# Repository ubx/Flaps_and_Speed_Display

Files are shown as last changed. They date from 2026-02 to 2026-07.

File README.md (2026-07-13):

# Flaps and Speed Display

An ESP32-S3-based flight instrument displays ([ESP32-S3-Touch-AMOLED-1.75](https://www.waveshare.com/wiki/ESP32-S3-Touch-AMOLED-1.75)) for flaps and speed data.
It uses an AMOLED display with LVGL to provide a graphical gauge for indicated airspeed (IAS) \
and flap position, receiving real-time data via the CAN bus (TWAI).

## Housing
[3D model](housing)

## PCB
[KiCad project](https://github.com/ubx/Flaps_and_Speed_Display_HW)

## Firmware and Polar Data Uploader
[Android app](https://github.com/ubx/Flaps_and_Speed_Display_Uploader) to upload firmware and polar data to the device.

### todo
- ~~adjust speed gauge size and layout~~
- ~~replace the numeric speed field~~
- ~~read and display the actual flap position (flap)~~
- ~~calculate and display the optimal flap position (flaputils::get_optimal_flap)~~
- ~~show display stale when nothing is received after 10 sec~~
- ~~design a graphical actual/optimal display~~
- ~~on start show about screenwith firmware and version~~
- setup screen ~~with brightness~~, ~~select polare~~...
- ~~implement update ventus3_defaut.json OTA with BLE~~
- demo mode
- ~~special flap positions for start and landing~~
- ~~3D print housing~~
- ~~PCB board~~
- ~~User Manual~~
- ~~Altitude screen~~
- ~~PCB rework, make it more professional!~~

Next steps:
- ~~xtent of polar data (JSON files) including speed limitations (minimum, optimal, and never-exceed)~~
- ~~improve speed screen with speed limits~~
- ~~enhance speed screen #1 similar to a real ASI~~

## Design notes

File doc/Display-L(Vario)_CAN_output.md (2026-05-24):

# Display-S(Vario) Settings for a Ventus3

| Index | Volt | Symbol |
|---|-----:|---|
| 0 |  0.0 | L |
| 1 |  0.5 | +2 |
| 2 |  1.3 | +1 |
| 3 |  2.3 | 0 |
| 4 |  3.0 | -1 |
| 5 |  3.3 | -2 |
| 6 |  3.6 | S |
| 7 |  4.0 | S1 |

# CAN Output on CanId 340
````
Frame 97: 16 bytes on wire (128 bits), 16 bytes captured (128 bits) on interface can0, id 0
Controller Area Network, ID: 340 (0x154), Length: 6
CANaerospace Protocol Data
CANaerospace
CAN ID: Flaps Position (340)
Node ID: AHRS (1)
Data Type: UCHAR2 (19)
Service Code: SC0 (0)
Message Code: 95
Data: 131 %, index 2
````
> [!Note]
> ``Data: 131 %`` should read as ``Data: 1.3 V``

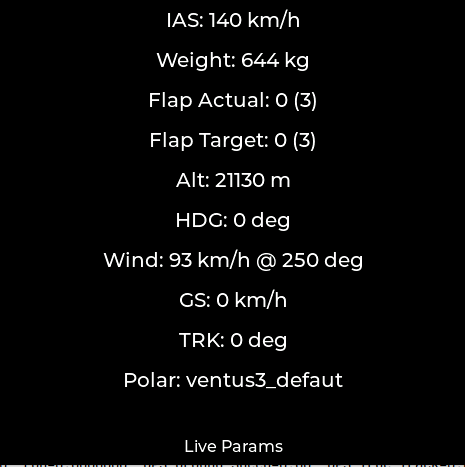
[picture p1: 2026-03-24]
doc/Life_Params.png

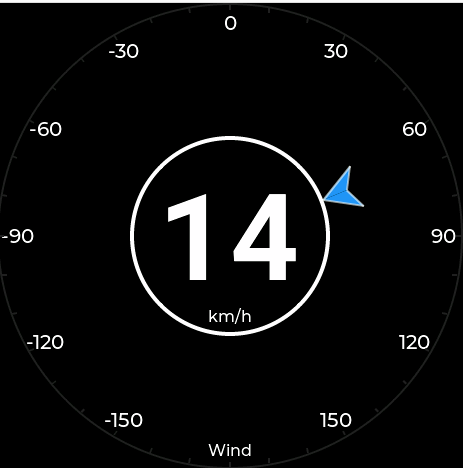
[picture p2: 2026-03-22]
doc/wind.png

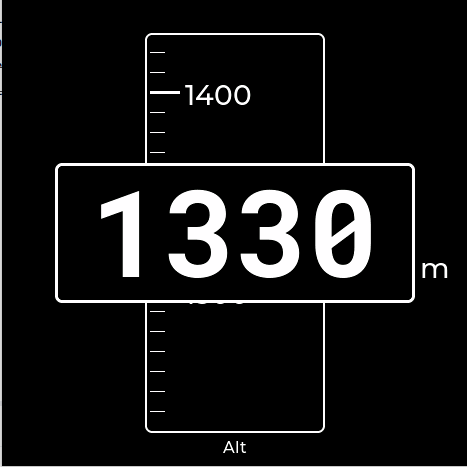
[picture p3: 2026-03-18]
doc/Altitude.png

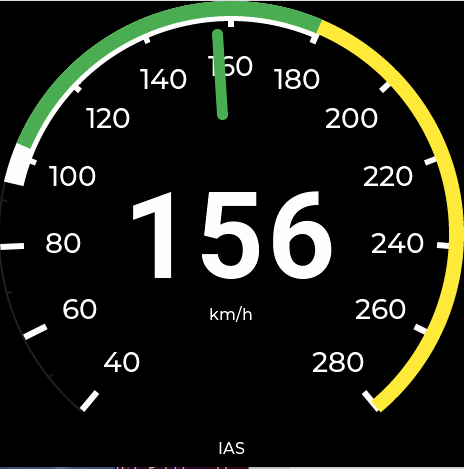
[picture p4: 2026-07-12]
doc/Speed.png

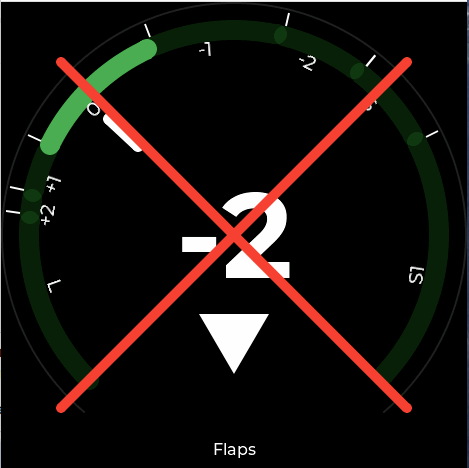
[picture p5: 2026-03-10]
doc/Flaps-Stale.png

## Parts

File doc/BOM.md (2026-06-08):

| # | Qty | Component | Size | Description  |
|---|-----|---|---|---|
| 1 | 3 | Linsenkopfschraube | M2 x 5 0 | ------------ |
 |

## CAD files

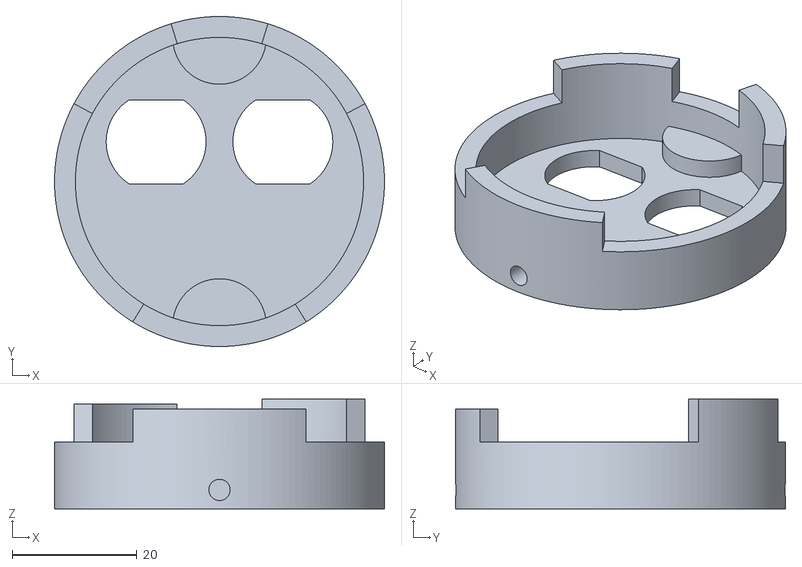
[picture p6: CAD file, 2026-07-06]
housing/57mm Instrument Flaps&Speed - Part 3.stl
52.9 x 52.9 x 17.6

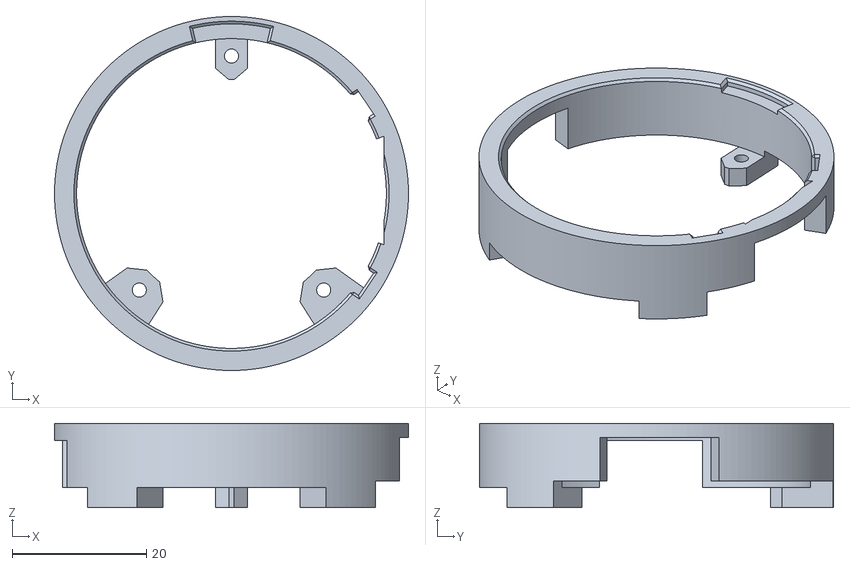
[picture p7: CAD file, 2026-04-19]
housing/57mm Instrument Flaps&Speed - Part 2.stl
52.8 x 52.8 x 12.6

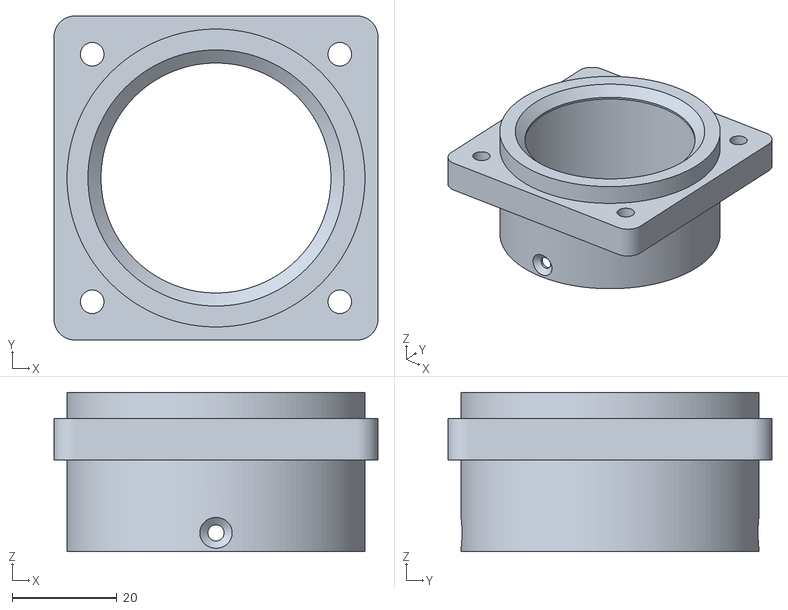
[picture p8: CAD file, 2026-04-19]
housing/57mm Instrument Flaps&Speed - Part 1.stl
62.0 x 62.0 x 30.5

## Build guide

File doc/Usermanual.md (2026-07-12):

# Flaps & Speed Display User Manual

**Document version:** 1.1  
**Date:** 24.03.2026

## Purpose

The **Flaps & Speed Display** is a touchscreen flight display for the ESP32-S3 AMOLED unit. It receives live data from the CAN bus and shows:

- indicated airspeed (IAS)
- current flap setting
- recommended flap setting
- flight altitude
- wind information (speed and relative direction)
- display brightness settings

The display is controlled entirely by touch gestures and on-screen buttons.

## Startup

After power-up, the unit shows a short splash screen with:

- application name
- firmware version
- git revision

It then switches to the normal operating screens.

## Touch Navigation

The display has seven screens. Navigation is done with swipe gestures:

- **Swipe up or down**: cycle between the four main flying screens (Speed, Flaps, Altitude, Wind)
- **Swipe right**: open the settings/detail screens
- **Swipe right again**: cycle between the three settings/detail screens (Settings, Live Params, Polar Files)
- **Swipe left**: return from the settings/detail screens to the main flying screen

## Screen Overview

### 1. Flaps Screen
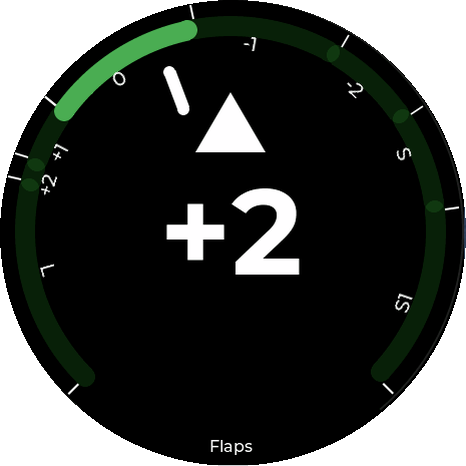
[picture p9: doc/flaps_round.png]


This screen combines airspeed with flap guidance.

- The large text in the center is the **actual flap position symbol**
- The white pointer still shows **IAS**
- The green arc marks the valid speed bands for the flap schedule
- The highlighted arc segment shows the **target flap range**
- The white triangle indicates the correction direction:
  - triangle above: select a **higher** flap setting
  - triangle below: select a **lower** flap setting
  - no triangle: actual and target flap settings match

Typical flap symbols are `L`, `+2`, `+1`, `0`, `-1`, `-2`, `S`, and `S1`.

The current configuration also defines a special **lowspeed** setting in the selected polar file (e.g., `ventus3_defaut.json`):

- flap setting: `-1`
- speed range: `0 to 40 km/h`

This lowspeed setting is intended for takeoff and landing and is handled separately from the normal flap speed bands.

### 2. Speed Screen
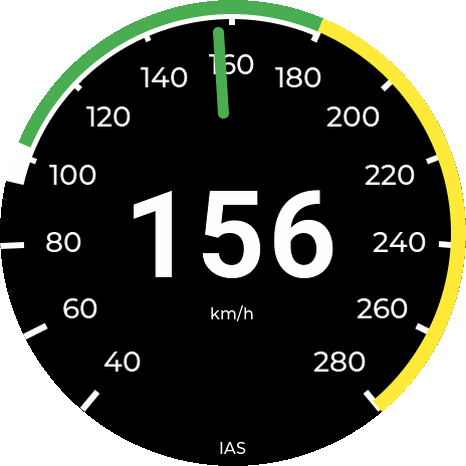
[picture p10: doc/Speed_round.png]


This is the airspeed display.

- The large number in the center is the **indicated airspeed** in **km/h**
- The white pointer shows the same IAS on the circular scale
- The scale range is **40 to 280 km/h**
- The pointer movement is intentionally damped for stable, instrument-like motion

Use this screen when you want the clearest possible IAS indication.

### 3. Altitude Screen
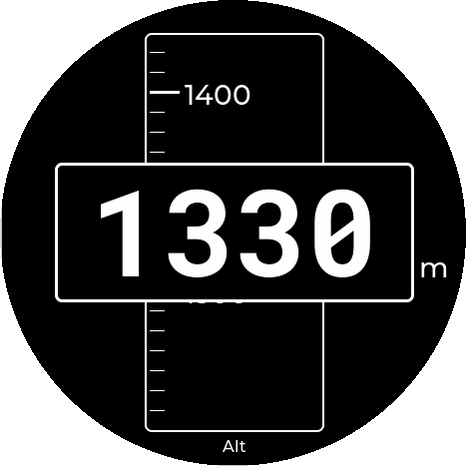
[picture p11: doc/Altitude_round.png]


This screen displays the current flight altitude.

- The large number in the center is the **altitude** in **meters**
- The moving tape in the center provides a visual representation of altitude changes
- The tape has major markings every **100 meters** and minor markings every **10 meters**
- The current altitude is also shown as a digital value in the center box for better readability

### 4. Wind Screen
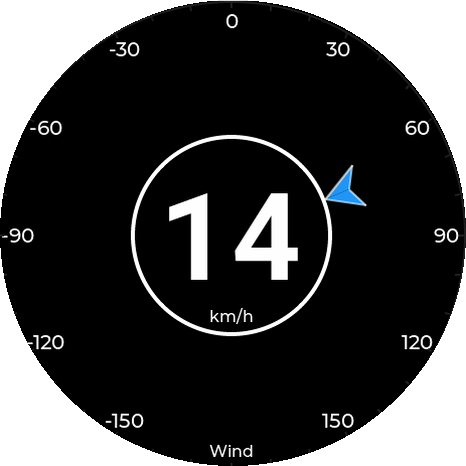
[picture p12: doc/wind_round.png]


This screen displays the current wind information relative to the aircraft's heading.

- The large number in the center is the **wind speed** in **km/h**
- The blue arrow on the circular scale shows the **relative wind direction**
- The scale range is **-180° to +180°** (0° is straight ahead)
- The arrow points in the direction the wind is coming from relative to the nose of the aircraft

### 5. Live Params Screen
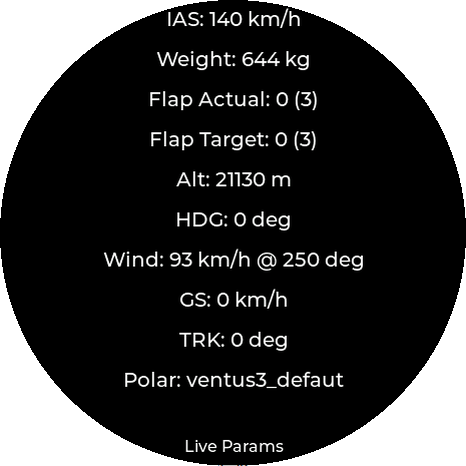
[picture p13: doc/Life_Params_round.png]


This screen shows the values used internally for flap guidance and navigation.

- **IAS**: indicated airspeed in km/h
- **Weight**: current flying weight used for the flap calculation
- **Flap Actual**: current detected flap symbol and index
- **Flap Target**: recommended flap symbol and index
- **Alt**: current altitude in meters
- **HDG**: current heading in degrees
- **Wind**: wind speed and absolute direction
- **GS**: ground speed in km/h
- **TRK**: GPS true track in degrees
- **Polar**: currently active flap schedule (polar file name)

This is the best screen for troubleshooting or checking why a flap recommendation or wind calculation is being made.

### 6. Settings / Brightness Screen
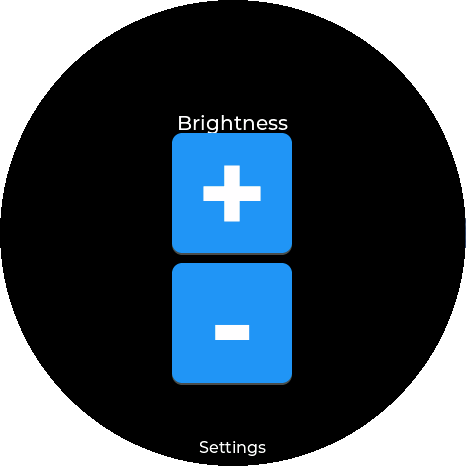
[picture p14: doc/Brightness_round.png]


This screen is used to adjust the display brightness.

- Press `+` to increase brightness
- Press `-` to decrease brightness

Brightness changes in **10% steps**.

- minimum brightness: **30%**
- maximum brightness: **100%**

### 7. Polar Files Screen
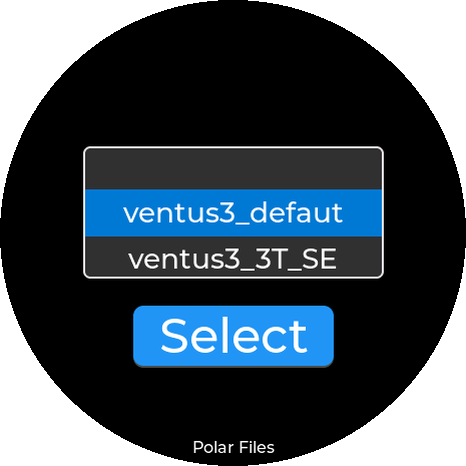
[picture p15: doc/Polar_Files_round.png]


This screen allows you to select the aircraft's polar file (flap schedule) from the files stored in the unit's internal memory (SPIFFS).

- The **roller** in the center lists all available `.json` files
- Use your finger to scroll through the list
- Press the **Select** button to load the highlighted polar

Once selected, the new polar is active immediately and will be remembered across power cycles.

#### Polar File: Speed Limits (`speedlimits`)

| Field | Meaning | Example value [km/h] |
| --- | --- |---:|
| **vso** | Stall speed in the landing configuration (full flaps, gear as applicable) | 94 |
| **vs1** | Stall speed in the clean configuration (flaps up) | 103 |
| **vfe** | Maximum flap extended speed | 180 |
| **vno** | Maximum structural cruising speed | 180 |
| **vne** | Never exceed speed | 280 |

See [Airspeed indicator](https://en.wikipedia.org/wiki/Airspeed_indicator). 
Values for a [Ventus-3F](https://www.google.com/url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)
and *FLUGHANDBUCH Ventus-3F „Sport“*

## How Flap Guidance Works

The unit compares:

- current IAS from CAN bus data
- current flap position from CAN bus data
- current weight from CAN bus data
- the flap schedule in the selected polar file (stored in SPIFFS)

## Stale Data Indication

If no relevant live data is received for **10 seconds**, the display marks the active flying screen as stale.

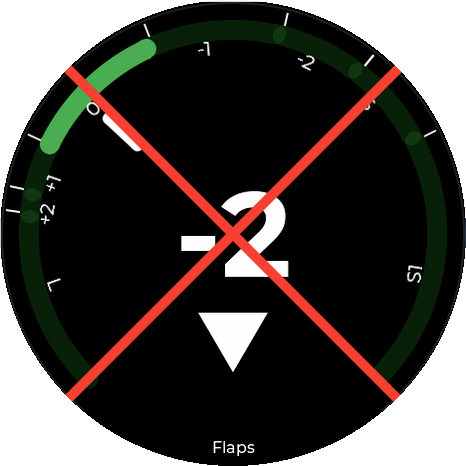
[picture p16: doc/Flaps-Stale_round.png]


The stale condition is shown by a large **red X** across the active screen.

This indicates that the shown IAS/flap information should no longer be trusted until valid CAN data is received again.

## Normal Use

1. Power on the unit.
2. Wait until the splash screen finishes.
3. Use the **Speed** screen for normal IAS monitoring.
4. Swipe to the **Flaps** screen when flap guidance is needed.
5. Swipe to the **Altitude** screen for height monitoring.
6. Swipe to the **Wind** screen to check wind conditions.
7. Open **Live Params** if you want to verify internal values.
8. Open **Polar Files** to select the correct aircraft model.
9. Open **Settings** to adjust brightness for cockpit conditions.

## Notes

- All speed values are displayed in **km/h**
- Flap recommendations depend on the flap polar stored in the JSON configuration
- If flap input data does not match a known position, the flap indication may show no valid symbol
- The guidance described in this manual is based on the Ventus 3 reference shown below (typically found in `ventus3_defaut.json`)
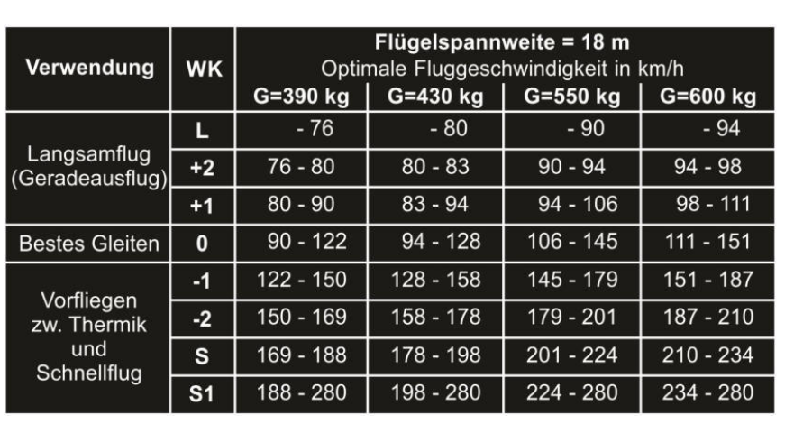
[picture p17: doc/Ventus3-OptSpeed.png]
-

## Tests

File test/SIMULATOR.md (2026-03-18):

# Simulator

`test/simulator.py` generates CAN frames directly on `can0`. It does not read from a log file.

## Sweep

The script iterates through this parameter sweep:

- `dry_and_ballast_mass`: `380` to `600 kg` (sent as `3800` to `6000`), increment `20` (`200`)
- `flaps`: `94, 167, 243, 84, 156, 191, 230, 250`
- `ias`: `10` to `280 km/h`, increment `10`

For each `(dry_and_ballast_mass, flaps, ias)` combination, it sends these CAN frames in order:

1. `dry_and_ballast_mass` on CAN ID `1515`
2. `flaps` on CAN ID `340`
3. `ias` on CAN ID `315`
4. `alt` on CAN ID `322`

## Encoding

- `dry_and_ballast_mass`: stored as big-endian unsigned 16-bit value in bytes `4..5` (value is 10 * kg)
- `flaps`: stored in byte `4`
- `ias`: input is in `km/h`, encoded as big-endian float in `m/s` in bytes `4..7`
- `alt`: input is in `m`, encoded as big-endian float in bytes `4..7`

Unused bytes are set to `0`.

## Timing

- `--time-gap <seconds>`: delay between each generated combination
- `--loop`: repeat the full sweep indefinitely

Without `--loop`, the script runs the sweep once and exits.

## Example

```bash
cd ..
python3 test/simulator.py --time-gap 1.0 --loop
```

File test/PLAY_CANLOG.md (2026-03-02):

### CAN Log Player Tool (`play_canlog.py`)

This document describes the `play_canlog.py` test tool, which simulates a CAN bus by playing back recorded messages from `canlog.log`.

### Overview
The `play_canlog.py` script reads the standard SocketCAN log format and sends the messages to the `can0` interface. It maintains the original timing gaps (2 seconds in the current log) between messages and provides decoded information on the terminal.

### Prerequisites

#### 1. Linux SocketCAN
The script uses native Linux SocketCAN support. It requires a `can0` interface to be available.

#### 2. Virtual CAN (vcan0) Setup
If you don't have a physical CAN interface, you can set up a virtual one and map it to `can0`. Run the following commands:
```bash
sudo modprobe vcan
sudo ip link add dev can0 type vcan
sudo ip link set up can0
```

### Usage

1. **Make the script executable**:
   ```bash
   chmod +x test/play_canlog.py
   ```

2. **Run the script**:
   ```bash
   cd ..
   ./test/play_canlog.py
   ```

3. **Optional Arguments**:
   - `--time-gap SECONDS`: Override the timing from the log file with a fixed delay between messages.
     ```bash
     cd ..
     ./test/play_canlog.py --time-gap 25
     ```

   - `--loop`: Loop the log file infinitely.
     ```bash
     cd ..
     ./test/play_canlog.py --loop
     ```

### Input File: `canlog.log`
The script reads from `test/canlog.log`. The log contains:
- **Flap positions** (ID 154 / 0x154): Values from `test_flaputils.cpp`.
- **Mass** (ID 1515 / 0x5EB): Constant value 4100.
- **IAS** (ID 315 / 0x13B): Ranging from 10 to 80 m/s with an increment of 3.

### Decoded Output
For each message sent, the script prints:
- The absolute timestamp from the log.
- The CAN ID and raw hex data.
- The human-readable parameter name and value (decoded according to `src/main.cpp`).

**Example output**:
```text
Playing test/canlog.log on can0...
[1740476040.000000] Sent ID 154 Data 000000005E000000 (flap: 94)
[1740476042.000000] Sent ID 5EB Data 0000000010040000 (dry_and_ballast_mass: 4100 Hg)
[1740476044.000000] Sent ID 13B Data 0000000041200000 (ias: 10.00 m/s)
...
```

### Notes
- The script uses **standard 11-bit CAN IDs** (non-extended).
- Multi-byte values (IAS, Mass) are encoded in **Big-Endian** format at byte index 4 of the CAN payload.

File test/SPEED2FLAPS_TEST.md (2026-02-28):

### SPEED2FLAPS_TEST

`speed2flaps_teste.py` is a PySide6-based graphical control panel used to simulate flight data (IAS, Mass, and Flaps) and transmit it over a SocketCAN interface. This tool is designed to test the `Flaps_and_Speed_Display` firmware by mimicking real-time CAN messages from a flight computer.

#### Features
- **IAS Control**: Adjust Indicated Airspeed (40–279 km/h). Sends CAN ID `315` (float, m/s).
- **Mass Control**: Adjust Glider Mass (390–600 kg). Sends CAN ID `1515` (uint16, Hg).
- **Flaps Control**: Select from predefined flap sensor voltage values. Sends CAN ID `340` (uint8).
- **Real-time Transmission**: Automatically sends CAN frames to the `can0` interface upon any value change.

#### Requirements
- Python 3
- PySide6
- A Linux system with `can0` or `vcan0` configured.

#### Usage
```bash
cd ..
python3 test/speed2flaps_teste.py
```

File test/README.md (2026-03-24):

This directory contains the test suite for the `flaputils` library.

### How to run the test on Native Platform

#### Option A: PlatformIO (Recommended)
1. Ensure you have PlatformIO installed (`pip install platformio`).
2. Build the native environment:
   ```bash
   cd ..
   pio run -e native
   ```
3. Run the compiled program:
   ```bash
   cd ..
   .pio/build/native/program
   ```
   *Note: Ensure you are in the project root directory so the program can find `spiffs_data/ventus3_defaut.json`.*

#### Option B: Plain g++
1. Install `cJSON` (e.g., `sudo apt-get install libcjson-dev` on Ubuntu).
2. Compile from the project root:
   ```bash
   cd ..
   g++ -std=c++17 -DNATIVE_TEST_BUILD -Isrc \
       test/test_flaputils.cpp src/flaputils.cpp \
       -lcjson -o test_flaputils
   ```
3. Run the executable:
   ```bash
   cd ..
   ./test_flaputils
   ```

### Notes
- The test loads data from `spiffs_data/ventus3_defaut.json`.
- It verifies empty mass, flap symbol lookup, and optimal flap interpolation.
- The same test file can also be run on ESP-IDF targets.

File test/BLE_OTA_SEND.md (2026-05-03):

# BLE OTA Sender (`test/ble_ota_send.py`)

This script sends data to the ESP32 BLE OTA service.

It supports two modes:

1. App firmware OTA (`--bin`)
2. SPIFFS file upload (`--spiffs-file` or `--spiffs-dir`)

Exactly one mode must be selected.

## Requirements

- Device is running firmware with BLE OTA service enabled.
- Device advertises as `Flaps-OTA` (or pass `--name` / `--address`).
- Python environment has `bleak` installed.

## Basic Usage

### 1) Firmware OTA (app partition)

```bash
cd ..
python test/ble_ota_send.py --bin .pio/build/esp32-s3-flaps/firmware.bin
```

Behavior:

- Sends `START` with size + CRC32.
- Streams firmware chunks over BLE.
- Sends `FINISH`.
- Sends `REBOOT` unless `--no-reboot` is set.

### 2) Upload SPIFFS files

#### Single file (`ventus3_defaut.json`)

```bash
cd ..
python test/ble_ota_send.py --spiffs-file spiffs_data/ventus3_defaut.json
```

Default remote target path: `/spiffs/ventus3_defaut.json`

#### Multiple files

```bash
cd ..
python test/ble_ota_send.py \
  --spiffs-file spiffs_data/ventus3_defaut.json \
  --spiffs-file spiffs_data/ventus3_3T_SE.json
```

#### All JSON files in a directory

```bash
cd ..
python test/ble_ota_send.py --spiffs-dir spiffs_data
```

Custom remote path (only for single file):

```bash
cd ..
python test/ble_ota_send.py \
  --spiffs-file spiffs_data/ventus3_defaut.json \
  --spiffs-remote /spiffs/ventus3_defaut.json
```

Behavior:

- Sends `START` with SPIFFS target metadata.
- Streams file content over BLE.
- Sends `FINISH`.
- Does not reboot in SPIFFS mode.

## Options

- `--name <ble_name>`: BLE advertised name (default: `Flaps-OTA`)
- `--address <mac_or_addr>`: connect directly without scanning
- `--bin <firmware.bin>`: firmware OTA mode
- `--spiffs-file <local_path>`: SPIFFS upload mode (can be repeated)
- `--spiffs-dir <dir_path>`: upload all .json files from directory
- `--spiffs-remote <remote_path>`: destination path for single file (default: `/spiffs/<filename>`)
- `--chunk <n>`: transfer chunk size in bytes (default: `240`)
- `--data-with-response`: send DATA writes with response (slower, can be more reliable)
- `--no-reboot`: skip reboot after firmware upload

## Notes

- For firmware mode, a BLE disconnect right after the reboot command can be normal.
- For SPIFFS mode, destination must be under `/spiffs/`.

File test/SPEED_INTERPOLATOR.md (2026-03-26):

### SPEED_INTERPOLATOR

`speed_interpolator.py` is a command-line tool designed to calculate the optimal speed range for a glider based on its current aircraft weight and flap setting. It uses a square-root scaling interpolation method to provide accurate speed recommendations across different weight configurations using data from a polar JSON file.

#### Features
- **Weight-Based Interpolation**: Automatically interpolates between provided weight points in the polar data using square-root scaling.
- **Flap Selection**: Supports various flap settings (e.g., L, +2, 0, -1, S) as defined in the JSON configuration.
- **Clamping**: Automatically clamps to the minimum or maximum weight available in the polar data if the specified weight is out of range.
- **JSON Integration**: Works with the standard glider polar JSON format used in the project.

#### Requirements
- Python 3

#### Usage
The script requires the path to a JSON polar file, the aircraft weight, and the flap setting.

```bash
python3 test/speed_interpolator.py <json_file> --weight <weight_kg> --wk <flap_setting>
```

**Example:**
```bash
cd ..
python3 test/speed_interpolator.py spiffs_data/ventus3_defaut.json --weight 500 --wk +1
```

**Output:**
```text
Weight: 500.0 kg
Flap setting: +1
Recommended speed: 89.6 – 101.2 km/h
```

#### JSON Data Structure
The tool expects a JSON file containing a `speedpolar` section with the following structure:
- `gewicht_kg`: A list of reference weights.
- `bereiche`: A list of flap setting entries, each containing:
    - `wk`: The flap setting identifier.
    - `geschwindigkeit`: A dictionary mapping weight strings to speed range pairs `[min_speed, max_speed]`.

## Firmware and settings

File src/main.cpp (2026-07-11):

#include "flight_data.hpp"
#include "can_decoder.hpp"
#include "flaputils.hpp"
#include "ui/ui.h"
#include "ui/ui_helpers.hpp"
#include "ui/screens/screen1.hpp"
#include "ui/screens/screen2.hpp"
#include "ui/screens/screen3.hpp"
#include "ui/screens/screen4.hpp"
#include "ui/screens/screen5.hpp"
#include "ui/screens/screen6.hpp"
#include "ui/screens/screen7.hpp"

#ifndef NATIVE_TEST_BUILD
#include <cstdio>
#include <cstdint>
#include <mutex>
#include <string>
#include "freertos/FreeRTOS.h"
#include "freertos/task.h"
#include "driver/twai.h"
#include "esp_timer.h"
#include "esp_log.h"
#include "esp_spiffs.h"
#include "esp_task_wdt.h"
#include "nvs_flash.h"
#ifdef ENABLE_DIAGNOSTICS
#include "esp_partition.h"
#include <dirent.h>
#endif
#include "ble_ota.hpp"
#include "bsp/esp32_s3_touch_amoled_1_75.h"
#include "lvgl.h"

#else

#include <algorithm>
#include <atomic>
#include <chrono>
#include <cmath>
#include <csignal>
#include <cstdlib>
#include <cstdio>
#include <cstring>
#include <cerrno>
#include <mutex>
#include <string>
#include <thread>
#include <vector>
#include <sys/ioctl.h>
#include <sys/socket.h>
#include <sys/time.h>
#include <unistd.h>
#include <linux/can.h>
#include <linux/can/raw.h>
#include <net/if.h>
#include "lvgl.h"
#include "platform/ui_platform.hpp"
#include "ui/screens/screen1.hpp"
#include "ui/screens/screen3.hpp"
#include "ui/screens/screen4.hpp"
#endif

#define APP_NAME "Flaps & Speed"
#define APP_VERSION "1.0.4"

#ifndef GIT_REVISION
#define GIT_REVISION "unknown"
#endif

static const char* TAG = "main";
static FlightData g_flight_state;

#ifndef NATIVE_TEST_BUILD

class CANReceiver
{
public:
    CANReceiver(FlightData& flight_data) : flight_data(flight_data) {}

    void start()
    {
        xTaskCreatePinnedToCore(receive_task, "can_rx_task", 4096, this, 5, nullptr, tskNO_AFFINITY);
    }

private:
    FlightData& flight_data;

    static void receive_task(void* arg)
    {
        auto self = static_cast<CANReceiver*>(arg);
        self->run();
    }

    [[noreturn]] void run() const
    {
        twai_message_t message;
        while (true)
        {
            if (twai_receive(&message, pdMS_TO_TICKS(1000)) == ESP_OK)
            {
                handle_message(message);
            }
        }
    }

    void handle_message(const twai_message_t& msg) const
    {
        if (!(msg.flags & TWAI_MSG_FLAG_EXTD))
        {
            switch (msg.identifier)
            {
            case 315: flight_data.update_float("ias", CANDecoder::decode_float(msg.data)); break;
            case 316: flight_data.update_float("tas", CANDecoder::decode_float(msg.data)); break;
            case 321: flight_data.update_float("heading", CANDecoder::decode_float(msg.data)); break;
            case 322: flight_data.update_float("alt", CANDecoder::decode_float(msg.data)); break;
            case 1519: flight_data.update_float("alt_corr", CANDecoder::decode_float(msg.data)); break;
            case 333: flight_data.update_float("wind_speed", CANDecoder::decode_float(msg.data)); break;
            case 334: flight_data.update_float("wind_direction", CANDecoder::decode_float(msg.data)); break;
            case 340: flight_data.update_int("flap", CANDecoder::decode_flap_idx(msg.data)); break;
            case 1039: flight_data.update_float("gps_ground_speed", CANDecoder::decode_float(msg.data)); break;
            case 1040: flight_data.update_float("gps_true_track", CANDecoder::decode_float(msg.data)); break;
            case 1515: flight_data.update_uint16("dry_and_ballast_mass", CANDecoder::decode_u16(msg.data)); break;
            case 1506: flight_data.update_uint16("enl", CANDecoder::decode_u16(msg.data)); break;
            default: break;
            }
        }
    }
};

static CANReceiver receiver(g_flight_state);

static void configure_task_wdt_for_ui(void)
{
#if CONFIG_ESP_TASK_WDT_EN && !CONFIG_FREERTOS_UNICORE
    esp_task_wdt_config_t twdt_cfg = {
        .timeout_ms = CONFIG_ESP_TASK_WDT_TIMEOUT_S * 1000,
        .idle_core_mask = (1U << 0),
#if CONFIG_ESP_TASK_WDT_PANIC
        .trigger_panic = true,
#else
        .trigger_panic = false,
#endif
    };

    esp_err_t ret = esp_task_wdt_reconfigure(&twdt_cfg);
    if (ret == ESP_OK)
    {
        ESP_LOGI(TAG, "Reconfigured TWDT to monitor IDLE0 only");
        return;
    }

    TaskHandle_t idle1 = xTaskGetIdleTaskHandleForCore(1);
    if (!idle1)
    {
        ESP_LOGW(TAG, "IDLE1 handle unavailable; TWDT reconfigure failed: %s", esp_err_to_name(ret));
        return;
    }

    ret = esp_task_wdt_delete(idle1);
    if (ret == ESP_OK || ret == ESP_ERR_NOT_FOUND)
    {
        ESP_LOGI(TAG, "Cleared IDLE1 watchdog subscription");
    }
    else
    {
        ESP_LOGW(TAG, "Failed to clear IDLE1 watchdog subscription: %s", esp_err_to_name(ret));
    }
#endif
}

[[noreturn]] void print_task(void* arg)
{
    auto data = static_cast<FlightData*>(arg);
    while (true)
    {
#ifndef ENABLE_DIAGNOSTICS
        print_flight_data(*data);
#endif
        vTaskDelay(pdMS_TO_TICKS(1000));
    }
}

extern "C" void app_main(void)
{
    configure_task_wdt_for_ui();

    esp_err_t err = nvs_flash_init();
    if (err == ESP_ERR_NVS_NO_FREE_PAGES || err == ESP_ERR_NVS_NEW_VERSION_FOUND)
    {
        ESP_ERROR_CHECK(nvs_flash_erase());
        err = nvs_flash_init();
    }
    ESP_ERROR_CHECK(err);

    vTaskDelay(pdMS_TO_TICKS(2000));

    esp_vfs_spiffs_conf_t conf = {
        .base_path = "/spiffs",
        .partition_label = "spiffs",
        .max_files = 5,
        .format_if_mount_failed = true
    };

    esp_err_t ret = esp_vfs_spiffs_register(&conf);
    if (ret != ESP_OK)
    {
        ESP_LOGE(TAG, "Failed to mount or format SPIFFS (%s)", esp_err_to_name(ret));
    }
    else
    {
        if (flaputils::load_persisted_data())
            ESP_LOGI(TAG, "Persisted polar data loaded successfully");
        else
        {
            std::string first_polar = flaputils::find_first_polar_path();
            if (!first_polar.empty())
            {
                if (flaputils::load_data(first_polar.c_str()))
                {
                    ESP_LOGI(TAG, "No persisted polar, loaded first available: %s", first_polar.c_str());
                    flaputils::save_polar_path(first_polar.c_str());
                }
            }
        }
    }

    ble_ota_init();

    twai_general_config_t g_config = TWAI_GENERAL_CONFIG_DEFAULT(static_cast<gpio_num_t>(TWAI_TX_GPIO),
        static_cast<gpio_num_t>(TWAI_RX_GPIO), TWAI_MODE_NORMAL);
    twai_timing_config_t t_config = TWAI_TIMING_CONFIG_500KBITS();
    twai_filter_config_t f_config = TWAI_FILTER_CONFIG_ACCEPT_ALL();

    if (twai_driver_install(&g_config, &t_config, &f_config) == ESP_OK && twai_start() == ESP_OK)
    {
        receiver.start();
        // xTaskCreate(print_task, "print_task", 4096, &g_flight_state, 2, nullptr);
        ui_init();
        set_label1(APP_NAME);
        set_label2("Version: " APP_VERSION);
        char lvgl_ver[32];
        std::snprintf(lvgl_ver, sizeof(lvgl_ver), "LVGL v%d.%d.%d", LVGL_VERSION_MAJOR, LVGL_VERSION_MINOR, LVGL_VERSION_PATCH);
        set_label3(lvgl_ver);
        set_label4("Git Rev: " GIT_REVISION);
        vTaskDelay(pdMS_TO_TICKS(5000));

        if (bsp_display_lock(-1) == ESP_OK)
        {
            lv_screen_load_anim(screen2_get(), LV_SCR_LOAD_ANIM_FADE_ON, 500, 0, false);
            bsp_display_unlock();
        }
    }
}

#else // NATIVE_TEST_BUILD

struct SimulatorConfig
{
    int start_screen = 2;
    bool auto_cycle = false;
    int cycle_seconds = 8;
    int splash_ms = 1500;
    std::string can_iface = "can0";
};

static std::atomic<bool> g_running{true};
static void handle_signal(int) { g_running = false; }

static int parse_int_arg(const char* value, int fallback) { return value ? std::atoi(value) : fallback; }

static SimulatorConfig parse_args(int argc, char** argv)
{
    SimulatorConfig cfg;
    for (int i = 1; i < argc; ++i)
    {
        if (std::strcmp(argv[i], "--screen") == 0 && i + 1 < argc)
            cfg.start_screen = std::clamp(parse_int_arg(argv[++i], cfg.start_screen), 1, 7);
        else if (std::strcmp(argv[i], "--auto-cycle") == 0)
            cfg.auto_cycle = true;
        else if (std::strcmp(argv[i], "--cycle-seconds") == 0 && i + 1 < argc)
            cfg.cycle_seconds = std::max(1, parse_int_arg(argv[++i], cfg.cycle_seconds));
        else if (std::strcmp(argv[i], "--can-iface") == 0 && i + 1 < argc)
            cfg.can_iface = argv[++i];
        else if (std::strcmp(argv[i], "--no-splash") == 0)
            cfg.splash_ms = 0;
        else if (std::strcmp(argv[i], "--help") == 0)
        {
            std::printf("Usage: %s [--screen 1..7] [--auto-cycle] [--cycle-seconds N] [--can-iface can0] [--no-splash]\n", argv[0]);
            std::exit(0);
        }
    }
    return cfg;
}

static lv_obj_t* get_screen_by_index(int screen)
{
    switch (screen)
    {
    case 1: return screen1_get();
    case 2: return screen2_get();
    case 3: return screen3_get();
    case 4: return screen4_get();
    case 5: return screen5_get();
    case 6: return screen6_get();
    case 7: return screen7_get();
    default: return screen2_get();
    }
}

static void load_screen(int screen, lv_screen_load_anim_t anim)
{
    if (!ui_platform_lock(-1)) return;
    lv_obj_t* target = get_screen_by_index(screen);
    if (target)
    {
#ifdef NATIVE_SIMULATOR
        (void)anim;
        lv_screen_load(target);
#else
        lv_screen_load_anim(target, anim, 250, 0, false);
#endif
    }
    ui_platform_unlock();
}

static int open_can_socket(const std::string& iface)
{
    const int fd = socket(PF_CAN, SOCK_RAW, CAN_RAW);
    if (fd < 0) return -1;

    ifreq ifr {};
    std::snprintf(ifr.ifr_name, IFNAMSIZ, "%s", iface.c_str());
    if (ioctl(fd, SIOCGIFINDEX, &ifr) < 0) { close(fd); return -1; }

    sockaddr_can addr {};
    addr.can_family = AF_CAN;
    addr.can_ifindex = ifr.ifr_ifindex;

    timeval timeout { .tv_sec = 1, .tv_usec = 0 };
    setsockopt(fd, SOL_SOCKET, SO_RCVTIMEO, &timeout, sizeof(timeout));

    if (bind(fd, reinterpret_cast<sockaddr*>(&addr), sizeof(addr)) < 0) { close(fd); return -1; }
    return fd;
}

static void can_receiver_task(std::string iface)
{
    const int fd = open_can_socket(iface);
    if (fd < 0) { g_running = false; return; }

    while (g_running.load())
    {
        can_frame frame {};
        const ssize_t nread = read(fd, &frame, sizeof(frame));
        if (nread < 0) { if (errno == EAGAIN || errno == EWOULDBLOCK) continue; break; }
        if (nread != sizeof(frame) || (frame.can_id & CAN_EFF_FLAG)) continue;

        std::lock_guard lock(g_flight_state.mtx);
        switch (frame.can_id)
        {
        case 315:
            g_flight_state.ias = CANDecoder::decode_float(frame.data);
            g_flight_state.last_relevant_rx_ms = FlightData::monotonic_ms();
            break;
        case 316: g_flight_state.tas = CANDecoder::decode_float(frame.data); break;
        case 321: g_flight_state.heading = CANDecoder::decode_float(frame.data); break;
        case 322: g_flight_state.alt = CANDecoder::decode_float(frame.data); break;
        case 1519: g_flight_state.alt_corr = CANDecoder::decode_float(frame.data); break;
        case 333: g_flight_state.wind_speed = CANDecoder::decode_float(frame.data); break;
        case 334: g_flight_state.wind_direction = CANDecoder::decode_float(frame.data); break;
        case 340:
            g_flight_state.flapIdx = CANDecoder::decode_flap_idx(frame.data);
            g_flight_state.last_relevant_rx_ms = FlightData::monotonic_ms();
            break;
        case 354: g_flight_state.vario = CANDecoder::decode_float(frame.data); break;
        case 1039:
            g_flight_state.gps_ground_speed = CANDecoder::decode_float(frame.data);
            g_flight_state.last_relevant_rx_ms = FlightData::monotonic_ms();
            break;
        case 1040: g_flight_state.gps_true_track = CANDecoder::decode_float(frame.data); break;
        case 1515: g_flight_state.dry_and_ballast_mass = CANDecoder::decode_u16(frame.data); break;
        case 1506: g_flight_state.enl = CANDecoder::decode_u16(frame.data); break;
        default: break;
        }
    }
    close(fd);
    g_running = false;
}

static void pump_ui_for(std::chrono::milliseconds duration)
{
    const auto until = std::chrono::steady_clock::now() + duration;
    while (g_running.load() && std::chrono::steady_clock::now() < until)
    {
        const uint32_t sleep_ms = lv_timer_handler();
        std::this_thread::sleep_for(std::chrono::milliseconds(std::clamp<uint32_t>(sleep_ms, 1, 10)));
    }
}

static void print_task_native(FlightData* data)
{
    while (g_running.load())
    {
        print_flight_data(*data);
        std::this_thread::sleep_for(std::chrono::seconds(1));
    }
}

int main(int argc, char** argv)
{
    std::signal(SIGINT, handle_signal);
    std::signal(SIGTERM, handle_signal);
    const SimulatorConfig cfg = parse_args(argc, argv);

    if (!flaputils::load_persisted_data())
    {
        std::string first_polar = flaputils::find_first_polar_path();
        if (!first_polar.empty())
        {
            if (flaputils::load_data(first_polar.c_str()))
            {
                flaputils::save_polar_path(first_polar.c_str());
            }
        }
        else
        {
            if (!flaputils::load_data("spiffs_data/ventus3_defaut.json")) return 1;
        }
    }

    std::thread can_thread(can_receiver_task, cfg.can_iface);
    std::thread print_thread(print_task_native, &g_flight_state);

    ui_init();
    set_label1(APP_NAME);
    set_label2("Version: " APP_VERSION);
    char lvgl_ver[32];
    std::snprintf(lvgl_ver, sizeof(lvgl_ver), "LVGL v%d.%d.%d", LVGL_VERSION_MAJOR, LVGL_VERSION_MINOR, LVGL_VERSION_PATCH);
    set_label3(lvgl_ver);
    set_label4("Git Rev: " GIT_REVISION);

    if (cfg.splash_ms > 0) pump_ui_for(std::chrono::milliseconds(cfg.splash_ms));
    load_screen(cfg.start_screen, LV_SCR_LOAD_ANIM_FADE_ON);

    auto next_cycle = std::chrono::steady_clock::now() + std::chrono::seconds(cfg.cycle_seconds);
    int current_screen = cfg.start_screen;

    while (g_running.load())
    {
        const uint32_t sleep_ms = lv_timer_handler();
        if (cfg.auto_cycle && std::chrono::steady_clock::now() >= next_cycle)
        {
            current_screen = (current_screen % 4) + 1;
            load_screen(current_screen, LV_SCR_LOAD_ANIM_FADE_ON);
            next_cycle = std::chrono::steady_clock::now() + std::chrono::seconds(cfg.cycle_seconds);
        }
        std::this_thread::sleep_for(std::chrono::milliseconds(std::clamp<uint32_t>(sleep_ms, 1, 10)));
    }
    can_thread.join();
    print_thread.join();
    return 0;
}

#endif // NATIVE_TEST_BUILD

float get_ias_kmh() { return ::get_ias_kmh(g_flight_state); }
float get_weight_kg() { return ::get_weight_kg(g_flight_state); }
float get_alt_m() { return ::get_alt_m(g_flight_state); }
float get_heading() { return ::get_heading(g_flight_state); }
float get_wind_speed_kmh() { return ::get_wind_speed_kmh(g_flight_state); }
float get_wind_direction() { return ::get_wind_direction(g_flight_state); }
float get_gps_ground_speed_kmh() { return ::get_gps_ground_speed_kmh(g_flight_state); }
float get_gps_true_track() { return ::get_gps_true_track(g_flight_state); }
flaputils::FlapSymbolResult get_flap_actual() { return ::get_flap_actual(g_flight_state); }
flaputils::FlapSymbolResult get_flap_target() { return ::get_flap_target(g_flight_state); }
bool is_stale() { return g_flight_state.is_stale(); }

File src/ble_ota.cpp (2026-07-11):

#include "ble_ota.hpp"

#ifndef NATIVE_TEST_BUILD

#include <array>
#include <cstdio>
#include <cstdint>
#include <cstring>
#include <mutex>

#include "esp_log.h"
#include "esp_ota_ops.h"
#include "esp_system.h"
#include "esp_crc.h"
#include "esp_bt.h"
#include "nvs_flash.h"
#include "freertos/FreeRTOS.h"
#include "freertos/task.h"
#include "freertos/timers.h"

#if defined(CONFIG_BT_ENABLED) && CONFIG_BT_ENABLED && defined(CONFIG_BT_NIMBLE_ENABLED) && CONFIG_BT_NIMBLE_ENABLED
#include "host/ble_hs.h"
#include "host/util/util.h"
#include "nimble/nimble_port.h"
#include "nimble/nimble_port_freertos.h"
#include "services/gap/ble_svc_gap.h"
#include "services/gatt/ble_svc_gatt.h"

namespace
{
static const char* TAG = "ble_ota";

enum OtaCommand : uint8_t
{
    CMD_START = 0x01,  // [cmd][size_u32_le][crc32_u32_le][optional target_u8][optional path_len_u8][optional path_bytes]
    CMD_FINISH = 0x02, // [cmd]
    CMD_ABORT = 0x03,  // [cmd]
    CMD_REBOOT = 0x04  // [cmd]
};

enum OtaState : uint8_t
{
    STATE_IDLE = 0,
    STATE_IN_PROGRESS = 1,
    STATE_READY_TO_REBOOT = 2,
    STATE_ERROR = 3
};

enum TransferTarget : uint8_t
{
    TARGET_APP_OTA = 0x00,
    TARGET_SPIFFS_FILE = 0x02
};

struct __attribute__((packed)) OtaStatus
{
    uint8_t state;
    uint8_t error_code;
    uint16_t reserved;
    uint32_t expected_size;
    uint32_t received_size;
    uint32_t running_crc32;
};

static std::mutex s_mtx;
static OtaStatus s_status = {STATE_IDLE, 0, 0, 0, 0, 0};
static uint32_t s_internal_crc = 0;
static bool s_initialized = false;
static bool s_image_ready = false;
static esp_ota_handle_t s_ota_handle = 0;
static const esp_partition_t* s_update_partition = nullptr;
static FILE* s_spiffs_file = nullptr;
static TransferTarget s_transfer_target = TARGET_APP_OTA;
static uint32_t s_expected_crc32 = 0;
static uint8_t s_own_addr_type = BLE_OWN_ADDR_PUBLIC;

static uint16_t s_conn_handle = BLE_HS_CONN_HANDLE_NONE;
static uint16_t s_status_val_handle = 0;

static const ble_uuid128_t kServiceUuid =
    BLE_UUID128_INIT(0x39, 0x5d, 0xb0, 0x0a, 0x31, 0x14, 0x4f, 0x8b, 0xae, 0x2d, 0x4b, 0x7d, 0x30, 0xd6, 0xe4, 0x2a);
static const ble_uuid128_t kControlUuid =
    BLE_UUID128_INIT(0x39, 0x5d, 0xb0, 0x0b, 0x31, 0x14, 0x4f, 0x8b, 0xae, 0x2d, 0x4b, 0x7d, 0x30, 0xd6, 0xe4, 0x2a);
static const ble_uuid128_t kDataUuid =
    BLE_UUID128_INIT(0x39, 0x5d, 0xb0, 0x0c, 0x31, 0x14, 0x4f, 0x8b, 0xae, 0x2d, 0x4b, 0x7d, 0x30, 0xd6, 0xe4, 0x2a);
static const ble_uuid128_t kStatusUuid =
    BLE_UUID128_INIT(0x39, 0x5d, 0xb0, 0x0d, 0x31, 0x14, 0x4f, 0x8b, 0xae, 0x2d, 0x4b, 0x7d, 0x30, 0xd6, 0xe4, 0x2a);

static uint32_t read_le_u32(const uint8_t* p)
{
    return static_cast<uint32_t>(p[0]) |
           (static_cast<uint32_t>(p[1]) << 8U) |
           (static_cast<uint32_t>(p[2]) << 16U) |
           (static_cast<uint32_t>(p[3]) << 24U);
}

static uint8_t err_to_status(esp_err_t err)
{
    if (err == ESP_OK) return 0;
    if (err == ESP_ERR_INVALID_SIZE) return 2;
    if (err == ESP_ERR_INVALID_CRC) return 3;
    if (err == ESP_ERR_INVALID_STATE) return 4;
    return 1; // General error
}

static void update_status_locked(OtaState state, esp_err_t err)
{
    s_status.state = state;
    s_status.error_code = err_to_status(err);
}

static void notify_status_if_connected()
{
    if (s_conn_handle != BLE_HS_CONN_HANDLE_NONE && s_status_val_handle != 0)
    {
        ble_gatts_chr_updated(s_status_val_handle);
    }
}

static void abort_session_locked()
{
    if (s_status.state == STATE_IN_PROGRESS && s_ota_handle != 0)
    {
        esp_ota_abort(s_ota_handle);
    }
    s_ota_handle = 0;
    s_update_partition = nullptr;
    if (s_spiffs_file != nullptr)
    {
        fclose(s_spiffs_file);
        s_spiffs_file = nullptr;
    }
    s_image_ready = false;
}

static esp_err_t start_session_locked(uint32_t image_size, uint32_t expected_crc32,
                                      TransferTarget target, const char* spiffs_path)
{
    abort_session_locked();

    if (target == TARGET_APP_OTA)
    {
        s_update_partition = esp_ota_get_next_update_partition(nullptr);
        if (s_update_partition == nullptr)
        {
            ESP_LOGE(TAG, "No OTA app partition found. Add ota_0/ota_1 to partitions.csv.");
            update_status_locked(STATE_ERROR, ESP_ERR_NOT_FOUND);
            return ESP_ERR_NOT_FOUND;
        }

        esp_err_t err = esp_ota_begin(s_update_partition, image_size, &s_ota_handle);
        if (err != ESP_OK)
        {
            ESP_LOGE(TAG, "esp_ota_begin failed: %s", esp_err_to_name(err));
            update_status_locked(STATE_ERROR, err);
            return err;
        }
    }
    else if (target == TARGET_SPIFFS_FILE)
    {
        if (spiffs_path == nullptr || spiffs_path[0] == '\0')
        {
            update_status_locked(STATE_ERROR, ESP_ERR_INVALID_ARG);
            return ESP_ERR_INVALID_ARG;
        }
        if (strncmp(spiffs_path, "/spiffs/", 8) != 0)
        {
            ESP_LOGE(TAG, "SPIFFS path must start with /spiffs/: %s", spiffs_path);
            update_status_locked(STATE_ERROR, ESP_ERR_INVALID_ARG);
            return ESP_ERR_INVALID_ARG;
        }
        s_spiffs_file = fopen(spiffs_path, "wb");
        if (s_spiffs_file == nullptr)
        {
            ESP_LOGE(TAG, "Failed to open SPIFFS file for write: %s (errno: %d)", spiffs_path, errno);
            update_status_locked(STATE_ERROR, ESP_FAIL);
            return ESP_FAIL;
        }
    }
    else
    {
        update_status_locked(STATE_ERROR, ESP_ERR_INVALID_ARG);
        return ESP_ERR_INVALID_ARG;
    }

    s_status.expected_size = image_size;
    s_status.received_size = 0;
    s_status.running_crc32 = 0;
    s_internal_crc = 0;
    s_status.reserved = 0;
    s_expected_crc32 = expected_crc32;
    s_image_ready = false;
    s_transfer_target = target;
    update_status_locked(STATE_IN_PROGRESS, ESP_OK);
    ESP_LOGI(TAG, "BLE transfer started: target=%u expected_size=%lu expected_crc32=0x%08lx",
             static_cast<unsigned>(target),
             static_cast<unsigned long>(image_size),
             static_cast<unsigned long>(expected_crc32));
    return ESP_OK;
}
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

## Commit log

2026-02-10 Add CANReceiver implementation for handling TWAI messages
    Includes:
    - `FlightData` structure with thread-safe update methods for various data types.
    - `CANReceiver` class to process TWAI messages, decode data, and update `FlightData`.
    - Initialization of TWAI driver in `app_main`.
    - Background task for continuous message handling and processing.
2026-02-10 Add print_task for periodic FlightData logging
    - Thread-safe `FlightData::print` method for formatted console output.
    - `print_task` for logging flight data every second.
    - Task creation in `app_main`.
    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
2026-02-10 Switch to ESP32-S3-Zero board and add custom board definition
    - Updated PlatformIO configuration for ESP32-S3-Zero (FH4R2) with TWAI GPIO assignments.
    - Added `esp32-s3-fh4r2.json` custom board definition file.
    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
2026-02-11 Integrate SPIFFS support and enhance flap optimization logic
    - SPIFFS initialization in `app_main` with error handling and partition info logging.
    - JSON-driven flap data loading from SPIFFS.
    - Added `flaputils::get_optimal_flap` usage in `FlightData::print` for dynamic flap recommendations.
    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
    [main.cpp]
2026-02-11 Configure SPIFFS filesystem and partitions for ESP32-S3-Zero
    - Moved `data/flapDescriptor.json` to `spiffs_data/` directory.
    - Updated `platformio.ini` with `spiffs_data` directory, `src` path, and custom partitioning.
    - Added `partitions.csv` for defining memory layout.
    - Integrated `spiffs_create_partition_image` in `CMakeLists.txt`.
    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
    [partitions.csv]
2026-02-11 Enhance SPIFFS initialization and logging, improve `flaputils` error handling
    - Added detailed error messages in `flaputils` for file operations and JSON parsing.
    - Enhanced SPIFFS partition checks with logging of available partitions.
    - Improved `/spiffs` directory listing and added warnings for empty partitions.
    - Updated SPIFFS configuration in `app_main` with stricter error handling.
    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
    [main.cpp]
2026-02-11 Add SDK configuration for ESP32-S3-Zero
    - Generated `sdkconfig.esp32-s3-zero` file with default ESP-IDF 5.5.0 settings.
    - Enabled support for various peripherals, including ADC, I2C, UART, and SPI.
    - Configured custom partitions file (`partitions.csv`) and essential bootloader settings.
    - Optimized compiler and driver configurations for ESP32-S3-Zero.
    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
2026-02-11 Update `FlightData` to use `dry_and_ballast_mass` instead of `pilot_mass`
    - Renamed `pilot_mass` to `dry_and_ballast_mass` across the codebase for clarity and better terminology.
    - Updated related calculations, print formats, and case handling for consistency with new mass representation.
    - Adjusted `flaputils::get_optimal_flap` logic to reflect the new mass field.
    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
2026-02-11 Enable diagnostics and runtime stats for FreeRTOS tasks
    - Added `ENABLE_DIAGNOSTICS` flag in `platformio.ini` to control optional diagnostic features.
    - Enabled FreeRTOS runtime statistics and trace facility in `sdkconfig.esp32-s3-zero`.
    - Integrated diagnostics in `print_task`, SPIFFS partition checks, and file listing.
    - Added periodic FreeRTOS task runtime stats printing (every 10 cycles).
    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
2026-02-12 Refactor PlatformIO environments for reusability and add support for ESP32-S3-DevKitC-1
    - Introduced a shared `[env:base]` configuration for common settings.
    - Updated `[env:esp32-s3-zero]` to extend from base configuration.
    - Added new `[env:esp32-s3-flaps]` for ESP32-S3-DevKitC-1 with TWAI GPIO configuration.
    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
2026-02-12 Update PlatformIO config: Pin ESP32 platform version and enhance ESP32-S3-Flaps environment
    - Locked `platform` to `espressif32@^6.12.0` for consistent builds.
    - Added flash, PSRAM, and monitor settings for `[env:esp32-s3-flaps]`.
    - Defined 16MB flash size in build and upload configurations.
    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
2026-02-12 Update PlatformIO config and add `lv_conf.h` for LVGL configuration
    - Added `lv_conf.h` header file to `include/` for LVGL configuration.
    - Updated `platformio.ini` with new build flags (`-Iinclude`, `-std=gnu++20`, and `-DCOMPONENTS`).
    - Integrated `tool-cmake`, `tool-ninja`, and `framework-espidf` under `platform_packages`.
    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
2026-02-15 Adjust LCD resolution, update pin mappings, and add power control handling
    - Changed LCD resolution to 390x450 in `display.cpp`.
    - Updated QSPI pin mappings for new configuration.
    - Added power initialization logic for the LCD to stabilize power before use.
    - Resized LVGL gauge and center circle to match updated resolution.
2026-02-19 The diagnostics feature was enabled.
    1. Adding `-DENABLE_DIAGNOSTICS` to the `build_flags` in `platformio.ini` for both the `base` (ESP32) and `native` environments.
    2. Enabling `CONFIG_FREERTOS_GENERATE_RUN_TIME_STATS` and `CONFIG_FREERTOS_USE_STATS_FORMATTING_FUNCTIONS` in both `sdkconfig.defaults` and `sdkconfig.esp32-s3-flaps`. This allows the runtime task st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
2026-02-23 Fix Task Watchdog Triggered by IDLE1 on CPU1
    The task watchdog timeout was triggered because the LVGL task (running on CPU 1) was taking too long to complete its work in a single iteration, likely due to heavy rendering of the `lv_scale` widget combined with frequent UI updates.
    I have implemented the following changes to resolve the issue:
    1. **Optimized UI Timers:** In `screen1.cpp` and `screen2.cpp`, I added a check to `ui_update_timer_cb` to only execute the update logic if the respective screen is currently active (`lv_screen_active() == s_screen`). This prevents background screens from consuming CPU time.
    2. **Reduced Update Frequency:** I changed the UI update interval from 100ms (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
2026-02-25 test/canlog.log: Create a CAN log file `canlog.log` for use with `canplayer`.
    The log must include all positions from `test_positions[]` in `test_flaputils.cpp` (94, 95, 96, 97, 84, 85, 250, 252, 0, 230, 157, 167).
    Based on `main.cpp`, the CAN ID for flaps is 340 (0x154).
    The data format for ID 340 is `flight_data.update_int("flap", get_char(msg.data))`, where `get_char` returns `data[4]`.
    `canplayer -I canlog.log` expects the SocketCAN log format: `(timestamp) interface can_id#hex_data`.
    The time gap between entries should be 2 seconds.
    Next, I will verify the exact SocketCAN log format and generate the file.
2026-02-25 ui/screens/screen2: replaced all calls to `flaputils::get_flap_params()` with `flaputils::get_flap_speed_ranges(double gewicht_kg)`
    [main.cpp]
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2026-02-27 ui/screens/screen2: Fix performance problem #2.
    The primary goal was to reduce CPU load and prevent task watchdog triggers.
    ### Key Optimizations
    1. **Redundant Update Elimination (Change Detection):**
    * Implemented change detection in `ui_update_timer_cb` (the 5Hz timer) for flap indices and airspeed.
    * UI elements (labels, triangles, needle, and segment highlighting) are now only updated when their underlying data actually changes. This drastically reduces the number of LVGL style invalidations and layout calls.
    2. **Optimized Needle Rendering:**
    * Replaced dynamic retrieval of `lv_scale` properties (rotation, range, dimensions) with constants in `ui_set_line_needle_v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
2026-03-01 ui/screens/screen3: Replace slider with a button "+" to increase brightness and a button "-" to decrease brightness. Aligns vertical.
2026-03-01 ui/screens/screen2: Fixed a `task_wdt` (Task Watchdog Timer) timeout on CPU 1 within the `lvgl` task. #1
    - The issue was caused by heavy UI object recreation in `screen2.cpp` and a lack of watchdog resets during intensive rendering operations.
    ### Changes
    - Optimized `ui_create_screen2_deferred` in `src/ui/screens/screen2.cpp` by implementing object pooling/reuse for `lv_arc` objects instead of deleting and recreating them every 200ms.
    - Added `esp_task_wdt_reset()` calls within the `draw_variable_scale` loop to ensure the watchdog is fed during complex scale drawing.
    - Included `esp_task_wdt.h` to support manual watchdog management in the UI code.
    - Reduced the overall computational load o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
2026-03-01 ui/screens/screen2: Optimized to resolve a persistent `task_wdt` timeout on CPU 1.
    Reduced the frequency and threshold of heavy UI operations to minimize the rendering load on the LVGL task.
    - Reduced the main UI timer frequency for Screen 2 from 20Hz (50ms) to 10Hz (100ms), lowering the overall CPU demand for needle animation.
    - Increased the weight change threshold for rebuilding the flap speed scale from 0.001kg to 0.5kg to avoid redundant and expensive UI object updates.
    - Extended the deferred UI rebuild interval from 200ms to 1s (10x timer ticks) to further throttle intensive scale generation.
    - Adjusted internal update dividers to maintain 100ms responsiveness for label a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
2026-03-01 ui/screens/screen2: Further optimized to resolve persistent `task_wdt` timeouts on CPU 1.
    - Increased the frequency of watchdog resets during heavy UI construction and reduced the update frequency of non-critical UI elements.
    - Increased the frequency of `esp_task_wdt_reset()` calls in `ui_create_screen2_deferred` and `draw_variable_scale` to every 4 iterations (from 8), ensuring the watchdog is fed more often during complex UI builds.
    - Added new watchdog resets in the label rotation loop within `draw_variable_scale`.
    - Reduced the update frequency of flap labels and triangles from 10Hz to 5Hz (200ms) to lower the periodic rendering load.
    - These incremental changes ensure that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
2026-03-02 ui/screens/screen1/2/4: Fix LVGL TWDT by making stale overlays transition-based and non-destructive
    Optional body:
    - Replace stale overlay lv_obj_delete() in screen timers with transition-based hide/show.
    - Add overlay visibility state guards to avoid redundant LVGL updates.
    - Apply same stale overlay behavior consistently across screen1/screen2/screen4.
    - Keep stale criteria time-based (20s since last IAS/flap/GS update).
2026-03-02 Replaced double with float across the project, keeping double only for lat/lon paths in main.cpp.
    [main.cpp]
2026-03-03 Implement firmware update with BLE OTA
    [partitions.csv]
2026-03-04 Fix(wdt): prevent LVGL watchdog false positives and move TWDT policy to defaults.
    - guard esp_task_wdt_reset() calls so only subscribed tasks feed TWDT
    - pin LVGL task to CPU1 for stable scheduling
    - move TWDT timeout/core-idle policy to sdkconfig.defaults
    - keep board-specific sdkconfig.* values unchanged (defaults-driven)
    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
2026-03-04 main: fix(wdt): enforce runtime TWDT policy to ignore IDLE1 for LVGL core load.
    - decode WDT backtraces to LVGL software draw hot path (lv_draw_sw_arc/lv_refr)
    - add configure_task_wdt_for_ui() in app_main startup
    - call esp_task_wdt_reconfigure() with idle_core_mask = CPU0 only
    - fallback to esp_task_wdt_delete(IDLE1) when reconfigure fails
    - keep LVGL watchdog feeds guarded by task subscription status
    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
    [main.cpp]
2026-03-05 platformio: Due to simpler pcb layout, swap TX/RX gpio.
2026-03-05 Fixes "xtensa-esp-elf-g++: fatal error: cannot specify '-o' with '-c', '-S' or '-E' with multiple files"
    mkdir -p components
    cp -a managed_components/espressif__esp_lvgl_adapter components/espressif__esp_lvgl_adapter
    [partitions.csv]
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2026-03-09 Fix ESP32 UI platform linkage
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2026-03-18 flight_data, ui: Add support for corrected altitude (`alt_corr`) and integrate into display and calculations
    [main.cpp]
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2026-03-24 bsp/display: Adjust display configuration to fix PSRAM usage and transfer size issues
    [esp32_s3_touch_amoled_1_75.c]
2026-03-24 flaputils: Replace `flapDescriptor.json` with `ventus3_defaut.json` across project files and references
    [main.cpp]
2026-03-24 main: Initialize NVS flash storage and handle errors during initialization
    [main.cpp]
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2026-04-19 Add 3D models for 57mm Instrument Flaps & Speed
    [57mm Instrument Flaps&Speed - Part 1.stl, 57mm Instrument Flaps&Speed - Part 2.stl, 57mm Instrument Flaps&Speed - Part 3.stl]
2026-04-19 README.md: Add sections for Housing and PCB, fix minor typo.
2026-05-03 Remove flap position tolerance handling and refactor `get_flap_symbol` to use flap index
    [main.cpp]
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2026-06-08 ble_ota.cpp, ble_ota_send.py: Add delayed reboot using FreeRTOS timer and improve exception handling
    [ble_ota.cpp]
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2026-06-09 partitions.csv, ble_ota.cpp, main.cpp, ble_ota_send.py: Fix OTA partition typo, improve error handling, set preferred MTU, and ensure SPIFFS formatting on mount failure
    [partitions.csv]
2026-06-09 partitions.csv, ble_ota.cpp, main.cpp, ble_ota_send.py: Fix OTA partition typo, improve error handling, set preferred MTU, and ensure SPIFFS formatting on mount failure. Bump version.
    [partitions.csv]
2026-07-06 Update 3D models.
    [57mm Instrument Flaps&Speed - Part 3.stl]
2026-07-11 ble_ota.cpp, ble_ota_send.py: Enhance error handling, OTA status reporting, and data transmission reliability
    [ble_ota.cpp]
